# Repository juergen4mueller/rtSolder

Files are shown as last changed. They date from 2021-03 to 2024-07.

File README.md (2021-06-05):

# rtSolder

As I have the full Weller power for business I wanted to have a cheap solution to work with Wellers RT solder tips at home. Small package, a wide input voltage range, simple to use and scaleable power consumption have been targets of my project.
Final solution is a microchip PIC controller, reading the temperature signal which is processed by a TLV333 op amp, controlling a step down converter to regulate temperature and also drive the display.
Output power is adjustable in 10W steps from 10W to 40W. In 10W mode its also possible to use USB power. For higher power a higher voltage is necessary. Voltage maximum is 30V.

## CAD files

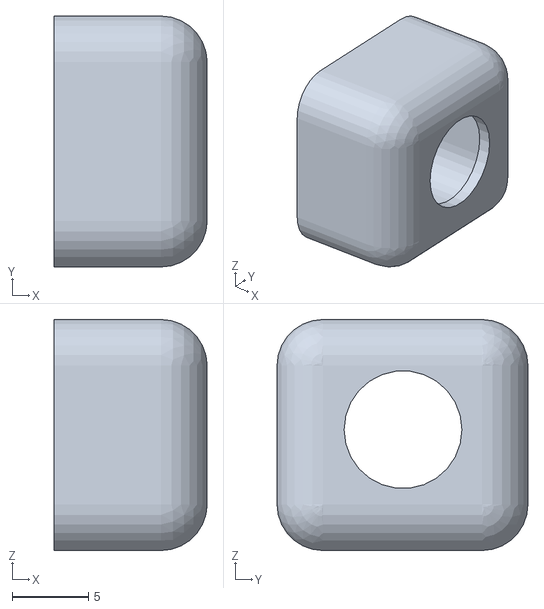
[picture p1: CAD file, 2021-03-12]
Housing/rtSolder_Back.stl
10.0 x 16.4 x 15.1

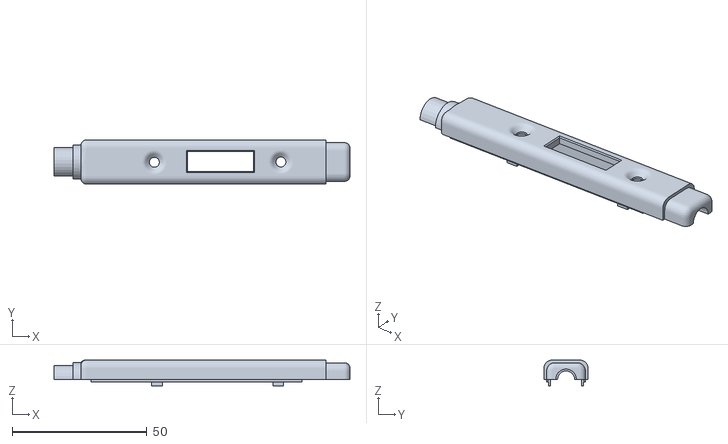
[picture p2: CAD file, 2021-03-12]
Housing/rtSolder_TOP.stl
110.0 x 16.4 x 9.60

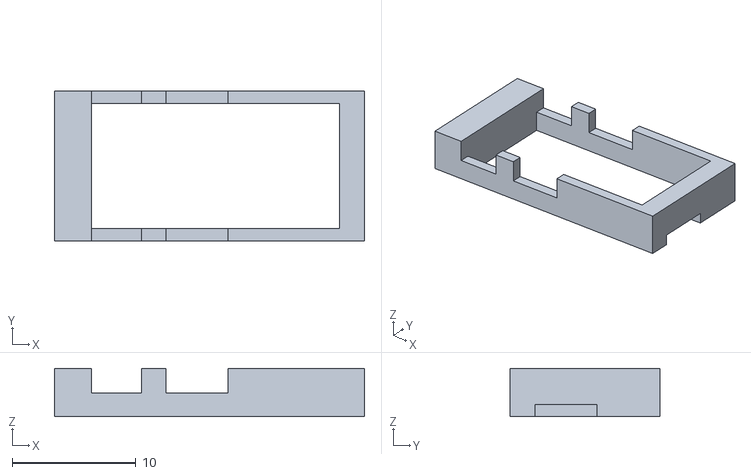
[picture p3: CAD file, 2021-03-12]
Housing/Display_Spacer_light.stl
25.0 x 12.1 x 3.90

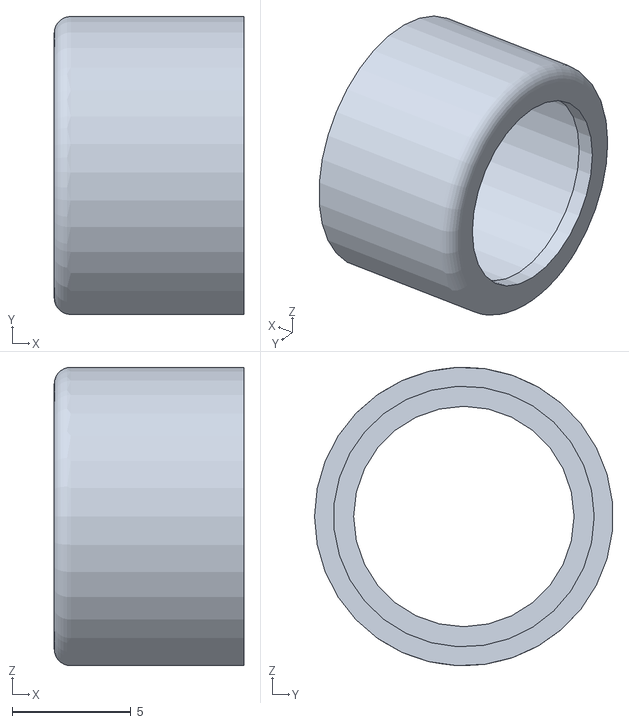
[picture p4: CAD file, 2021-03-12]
Housing/rtSolder_Front.stl
8.00 x 12.6 x 12.6

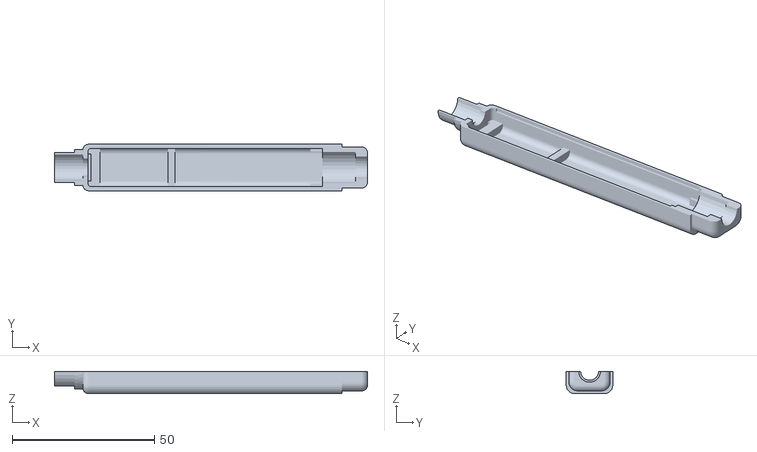
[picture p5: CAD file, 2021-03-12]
Housing/rtSolder_BTM.stl
110.0 x 16.4 x 7.90

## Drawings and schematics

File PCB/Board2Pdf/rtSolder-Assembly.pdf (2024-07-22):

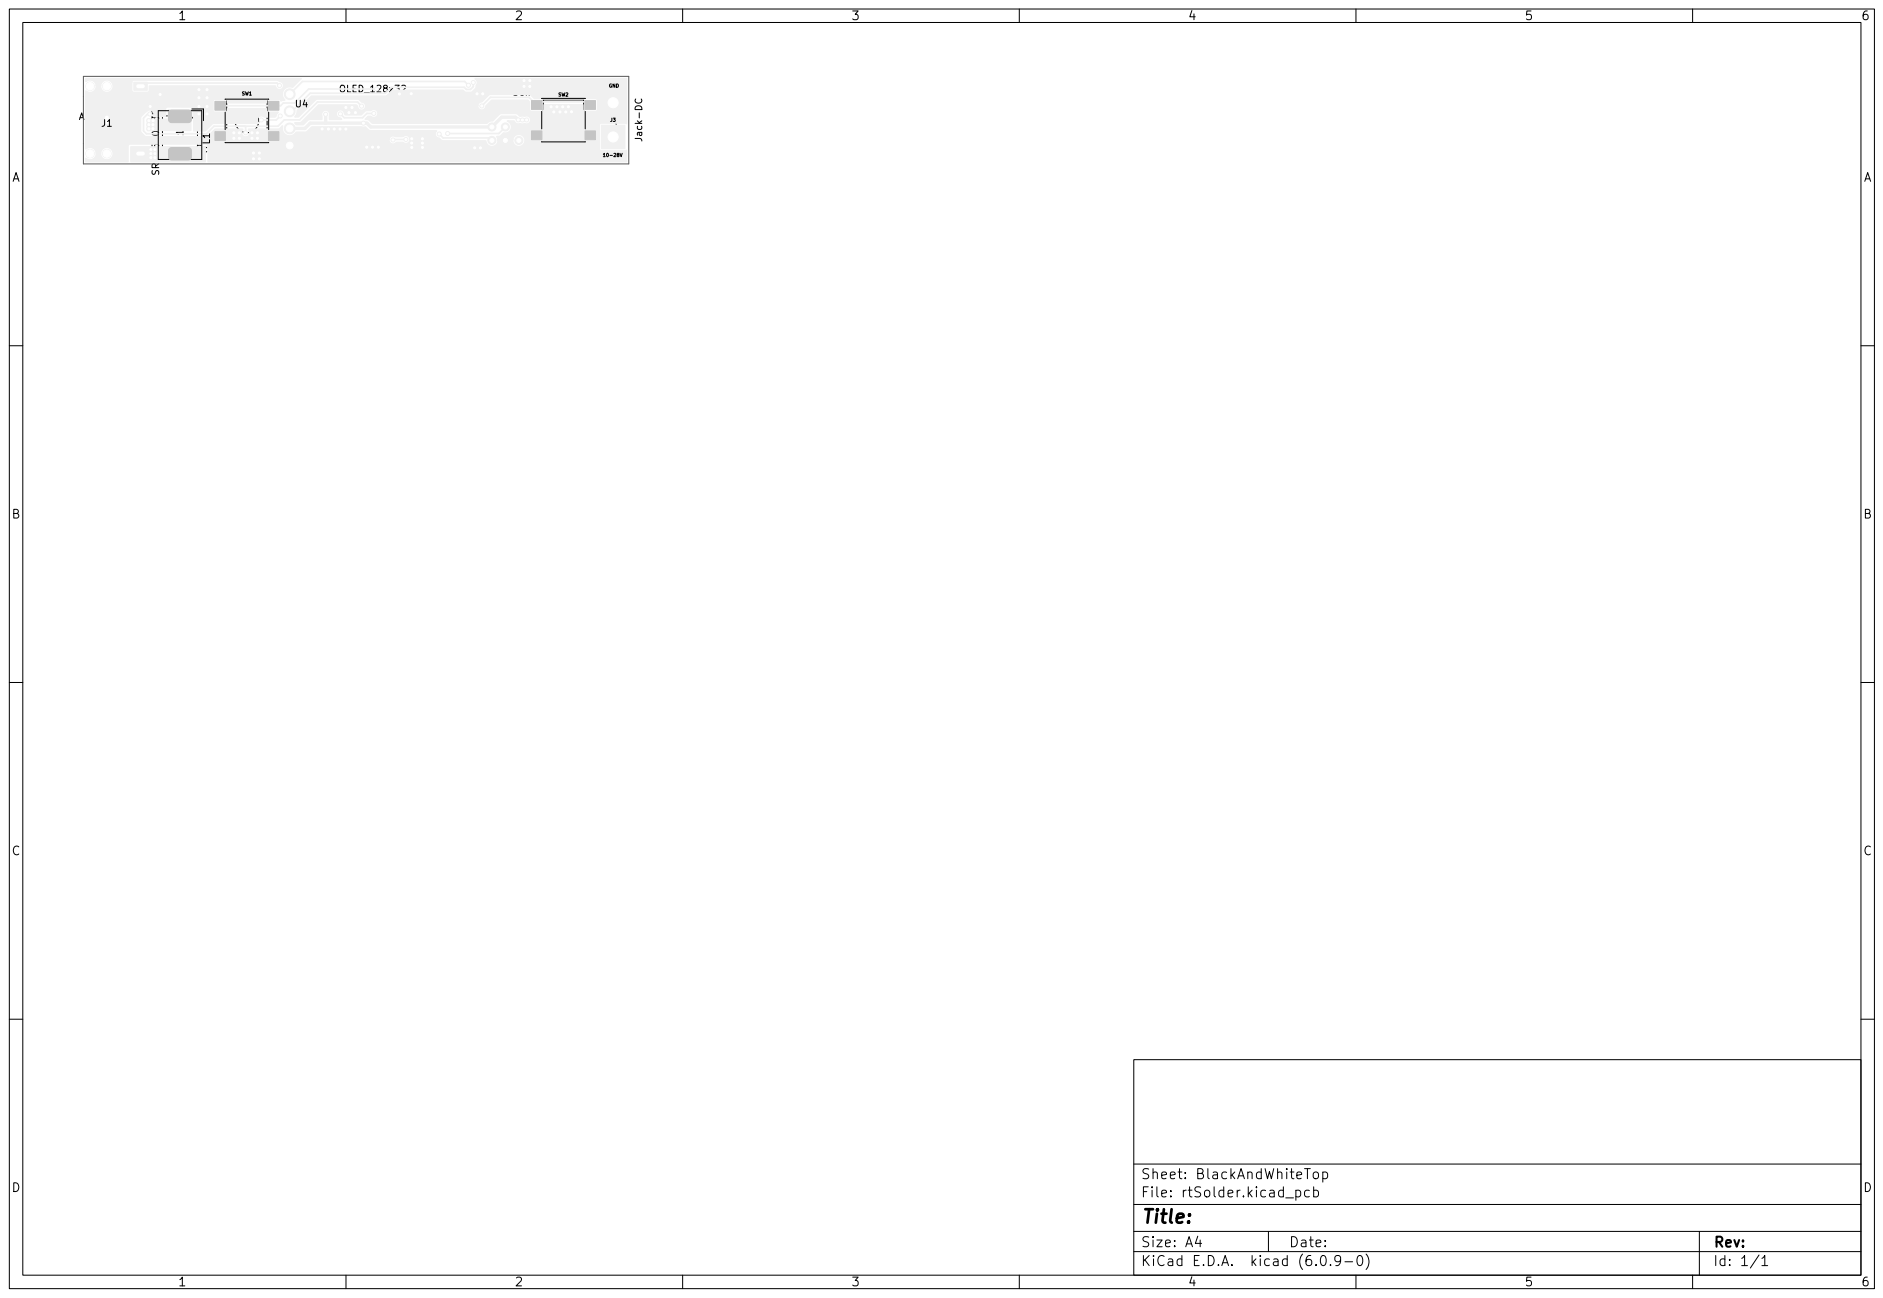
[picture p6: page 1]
D Date: KiCad E.D.A. kicad (6.0.9-0) Size: A4; Rev:; Id: 1/1 Title:; File: rtSolder.kicad_pcb; Sheet: BlackAndWhiteTop SRP⁶⁵⁴⁰⁻³R³M; Schurter_1301.9319 SW2; Jack⁻DC J3 Schurter_1301.9319 SW1 AudioJack3; OLED_128x32; 10-28V GND L1 SW2

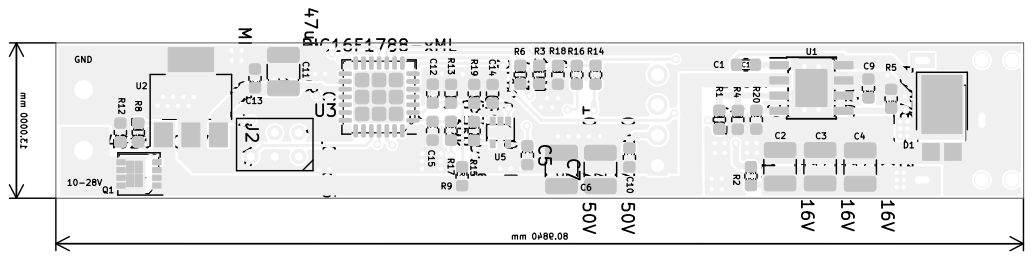
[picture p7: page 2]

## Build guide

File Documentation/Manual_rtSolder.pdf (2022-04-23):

# Bedienungsanleitung rtSolder

Bereich Versorgungsspannung 10 – 33 V
Leistung einstellbar zwischen 10 und 40 Watt (um an das verwendete Netzteil anpassen zu können) Temperatur einstellbar von 150 – 450 °C
DC-Hohlbuchse: 5,5mm/2,1mm
Lötspitze: Weller RT mit 3,5mm Klinkenstecker
Taster 1 | Display | Taster 2

Einschalten: Taster 2 kurz betätigen
Ausschalten: Taster 2 lang betätigen
Im ausgeschalteten Zustand können Leistung und gespeicherte Solltemperatur eingestellt werden. Dazu Taster 1 lang betätigen, bis das Menü erscheint. Hier kann mittels Taster 1 bzw. Taster 2 kurz die gewünschte Temperatur eingestellt werden.
Erneut Taster 1 lang betätigen, um zur Einstellung der Leistung zu gelangen. Hier kann mittels Taster 1 bzw. Taster 2 kurz die gewünschte Leistung eingestellt werden.
Erneut Taster 1 lang betätigen, um die Einstellungen zu speichern.
Mit langer Betätigung von Taster 2 kann das Setup verlassen werden, ohne die Werte zu ändern / speichern.

Im eingeschalteten Zustand kann die Solltemperatur eingestellt werden. Mittels Taster 1 bzw. Taster 2 kurz die gewünschte Temperatur einstellen.

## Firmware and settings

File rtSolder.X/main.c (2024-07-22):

/**
  Generated Main Source File

  Company:
    Microchip Technology Inc.

  File Name:
    main.c

  Summary:
    This is the main file generated using PIC10 / PIC12 / PIC16 / PIC18 MCUs

  Description:
    This header file provides implementations for driver APIs for all modules selected in the GUI.
    Generation Information :
        Product Revision  :  PIC10 / PIC12 / PIC16 / PIC18 MCUs - 1.76
        Device            :  PIC16F1788
        Driver Version    :  2.00
*/

/*
    (c) 2018 Microchip Technology Inc. and its subsidiaries. 
    
    Subject to your compliance with these terms, you may use Microchip software and any 
    derivatives exclusively with Microchip products. It is your responsibility to comply with third party 
    license terms applicable to your use of third party software (including open source software) that 
    may accompany Microchip software.
    
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
    IN NO EVENT WILL MICROCHIP BE LIABLE FOR ANY INDIRECT, SPECIAL, PUNITIVE, 
    INCIDENTAL OR CONSEQUENTIAL LOSS, DAMAGE, COST OR EXPENSE OF ANY KIND 
    WHATSOEVER RELATED TO THE SOFTWARE, HOWEVER CAUSED, EVEN IF MICROCHIP 
    HAS BEEN ADVISED OF THE POSSIBILITY OR THE DAMAGES ARE FORESEEABLE. TO 
    THE FULLEST EXTENT ALLOWED BY LAW, MICROCHIP'S TOTAL LIABILITY ON ALL 
    CLAIMS IN ANY WAY RELATED TO THIS SOFTWARE WILL NOT EXCEED THE AMOUNT 
    OF FEES, IF ANY, THAT YOU HAVE PAID DIRECTLY TO MICROCHIP FOR THIS 
    SOFTWARE.
*/

#include "mcc_generated_files/mcc.h"
#include "OLED/i2c1.h"
#include "OLED/lcd.h"
#include "OLED/font.h"
#include <stdio.h>
#include <string.h>

uint16_t loads_per_minute;
uint16_t time_counter;
uint16_t counter_200ms;
uint8_t counter_minutes;
//#define TEST_POWER_MODULE

__EEPROM_DATA(0x02/*default power*/, 0x35/*default temperature*/, 0x02/*auto off nach 5 min*/, 0xFF, 0xFF, 0xFF, 0xFF, 0xFF); // Fill first 8 bytes of EEPROM
/*            SW1                              SW2
            +++++++++                       +++++++++
 *          +       +    **************     +       +
 *          +   o   +    **************     +   o   +
 *          +       +    **************     +       +
 *          +++++++++                       +++++++++
 
 *          
 *          Menü ON   LP                    ON SP 
 *          Menü Skip LP                    OFF LP
 *          Temperatur -                  Temperatur +  
 * 
 *  Im Menü:
 *  - Solltemperatur gespeichert im EEPROM
 *  - Leistung      gespeichert im EEPROM
 *  - Zeit bis autom. abgeschalten wird
 * 
 * Bei 350 Grad:
 * 10W: 2-3
 * 20W: 4-5
 * 30W: 5-7
 * 40W: 8-10
 * 
 * Bei 400 Grad:
 * 10W: 
 * 20W: 
 * 30W: 
 * 40W: 
 *  
 * 
 */

/*
RC1+RC2 0 -> U = 9,1V P= 41 W (TIP_PS1+TIP_PS2)
RC1 0 ???> U = 7,4V P= 27W (TIP_PS1)
RC2 0 ???> U = 6,1V P= 18W (TIP_PS2)
nichts 0 ??> U = 4,4V P= 10W (kein TIP_PS geschalten)
*/

uint8_t counter2ms_solder, counter2ms_switch;
uint8_t tmr_2ms, tmr1_msg;
uint8_t Switch_1, Switch_2, Switch_1_alt, Switch_2_alt;
uint8_t counter_LP_SW1, counter_LP_SW2;
uint16_t Temperatur_TIP;
uint16_t U_Supply;
uint16_t TEMP_SOLL;
uint16_t AN_out;

uint16_t Temp_Anz_Filter[16];
uint8_t  Temp_Anz_pos;

char text_out[30];

extern uint16_t AN_IN_Temp, AN_IN_U_Supply;

uint8_t counter_left, counter_right;

uint8_t testmode;
uint8_t state_test;

uint8_t mode, mode_alt;
#define mode_startup 0x00
#define mode_off 0x01
#define mode_menue 0x02
#define mode_work  0x03

#define solder_display_normal   0x00
#define solder_display_dev      0x01
uint8_t solder_display_mode;

uint8_t EE_solltemperatur;  // Faktor 10
uint8_t EE_soll_Power;       // Faktor 10
#define Auto_off_disabled   0x00 
#define Auto_off_2_min      0x01
#define Auto_off_5_min      0x02
#define Auto_off_10_min     0x03
#define Auto_off_15_min     0x04
uint8_t EE_AutoOff;         //
uint8_t x;

void timer1_fired(void){
    tmr1_msg ++;
}

void init_system(void){
    counter2ms_solder = 0;
    solder_display_mode = solder_display_normal;
    testmode = 0;
#ifdef TEST_POWER_MODULE
    
#else
    initI2C();
    lcd_init();
#endif
    Temp_Anz_pos = 0;
    mode = mode_startup;
    EE_soll_Power = DATAEE_ReadByte(0x00);
    EE_solltemperatur = DATAEE_ReadByte(0x01);
    EE_AutoOff = DATAEE_ReadByte(0x02);
    
    if(EE_soll_Power > 4){
        EE_soll_Power = 4;
    }
    if(EE_soll_Power < 1){
        EE_soll_Power = 1;
    }
    if(EE_solltemperatur > 45){
        EE_solltemperatur = 35;
    }
    if(EE_AutoOff > Auto_off_15_min){
        EE_AutoOff = Auto_off_15_min;
    }
}


uint16_t calc_tip_temperatur(uint16_t adc_value){
    // ADC-Wert ist 12 Bit lang -> 0...4095
    // mit Referenzspannugn 2.048V (FVR) 500 µV pro Bit
    // Temperaturmessung: bei 450 Grad sind 7mV messbar
    // bei 7mV soll der ADC-Wert 3600 sein -> ADC-Wert / 8 ergibt Temperatur
    // -> 7mV am OP Eingang sollen 1,950 Volt am OP-Ausgang ergeben
    // Verstärkungsfaktor 261 -> 39kOhm und 150 Ohm
    uint16_t calcValue = adc_value;

    return ((calcValue >> 3)+20); // +20 da die Umgebungstemperatur schon 20 Grad beträgt
}
uint16_t calc_supply_voltage(uint16_t adc_value){
    // Messung soll bis 30V gehen (30/4095 = 7,33mV je Bit)
    // 30,0V -> 300 als Ergebnis (2400 / 8)
    // bei 30V sollen 1,2V am ADC anliegen
    // 56kOhm zu 2,2 kOhm -> Messfehler 1,8%
    return (adc_value >> 3);
}

#define sw1_short   0x01
#define sw1_long    0x10
#define sw2_short   0x02
#define sw2_long    0x20
#define sw1_u_sw2   0x04



/*            SW1                              SW2
            +++++++++                       +++++++++
 *          +       +    **************     +       +
 *          +   o   +    **************     +   o   +
 *          +       +    **************     +       +
 *          +++++++++                       +++++++++
 
 *          
 *          Menü ON   LP                    ON SP 
 *          Menü Skip LP                    OFF LP
 *          Temperatur -                  Temperatur +  
 * 
 *  Im Menü:
 *  - Solltemperatur gespeichert im EEPROM
 *  - Max. Strom     gespeichert im EEPROM
 * 
 * 
 * 
 *  OFF 
 * 
 */

unsigned char get_switch_state(void){
    // wird alle 2ms aufgerufen
    static uint8_t sw1, sw2, sw1_alt, sw2_alt;
    static uint8_t sw1_cnt, sw2_cnt;
    static uint8_t sw1_long_done, sw2_long_done;
    static uint8_t counter_switch;
    static uint8_t init_switch;
    uint8_t switch_state = 0;
    
    sw1 = IN_Switch1_GetValue();
    sw2 = IN_Switch2_GetValue();
    counter_switch ++;
    if(counter_switch >= 50){
        counter_switch = 0;
        // alle 100 ms
        init_switch = 1;
        
        if(sw1 == 0)sw1_cnt ++; else sw1_cnt = 0;
        if(sw2 == 0)sw2_cnt ++; else sw2_cnt = 0;
        
        if((sw1_cnt >= 10)&&(sw1_long_done == 0)){ switch_state = sw1_long; sw1_long_done = 1;} // longpress nach 1s
        if((sw2_cnt >= 10)&&(sw2_long_done == 0)){ switch_state = sw2_long; sw2_long_done = 1;} // longpress nach 1s
    }
    if((sw1==1)&&(sw1_alt==0)){
        if(sw1_long_done == 1){
            sw1_long_done = 0;
        }
        else{
            switch_state = sw1_short;
        }
    }
    if((sw2==1)&&(sw2_alt==0)){
        if(sw2_long_done == 1)
        sw2_long_done = 0;
        else
        switch_state = sw2_short;
    }
    
    sw1_alt = sw1;
    sw2_alt = sw2;
    if(init_switch) return switch_state;
    else return 0;
}
unsigned int test_power_to_display;
void proc_off(void){ // and test mode
    uint8_t switch_state = get_switch_state();
    static uint16_t counter_display_2ms;
    counter_display_2ms ++;
    
    if (switch_state == sw1_short) {
        if(testmode == 0){
            counter_left++;
        }
        else{
            testmode = 0;
            counter_display_2ms = 0;
        }
    }
    if(switch_state == sw1_long){    
        if(testmode == 0){
            // Enter Menu
            counter_left = 0;
            mode = mode_menue;
            counter_display_2ms = 0;
        }
        else{
            testmode = 0;
            counter_display_2ms = 0;
        }
    }
    else if(switch_state == sw2_short){   
        if(testmode != 0){
            state_test ++;
        }
        else{
            mode = mode_work;
            counter_left = 0;
            counter_minutes = 0;
            counter_200ms = 0;
            counter_display_2ms = 0;
        }
    }
    else if(switch_state == sw2_long){ 
        if(counter_left == 4){
            if(testmode != 0){
                testmode = 0;
            }
            else{
                testmode = 1;
                counter_200ms = 0;
                state_test = 0;
            }
        }
        else{
            mode = mode_work;
            counter_minutes = 0;
            counter_200ms = 0;
            counter_display_2ms = 0;
        }
        counter_left = 0;
    }
    
    if(testmode==1){
        // <editor-fold defaultstate="collapsed" desc="Testbetrieb">
        counter2ms_solder ++;
        if(counter2ms_solder == 4){
            ADC_StartConversion(AN2_Temp_Tip);
        }
        if(counter2ms_solder == 6){
            if(counter_200ms >= 200){
                state_test = 9; // Test automatisch nach 40 Sekunden beenden
            }
            switch(state_test){
                case 0:
                    test_power_to_display = 0;
                    TIP_SUPPLY_EN_SetLow();
                    TIP_PS1_SetLow();
                    TIP_PS1_SetDigitalInput();
                    TIP_PS2_SetLow();
                    TIP_PS2_SetDigitalInput();
                    break;
                case 1: // 10 Watt
                    test_power_to_display = 10;
                    TIP_SUPPLY_EN_SetHigh();
                    TIP_PS1_SetLow();
                    TIP_PS1_SetDigitalInput();
                    TIP_PS2_SetLow();
                    TIP_PS2_SetDigitalInput();
                    break;
                case 2: //Off
                    test_power_to_display = 0;
                    TIP_SUPPLY_EN_SetLow();
                    TIP_PS1_SetLow();
                    TIP_PS1_SetDigitalInput();
                    TIP_PS2_SetLow();
                    TIP_PS2_SetDigitalInput();
                    break;
                case 3: // 20 Watt
                    test_power_to_display = 20;
                    TIP_SUPPLY_EN_SetHigh();
                    TIP_PS1_SetLow();
                    TIP_PS1_SetDigitalInput();
                    TIP_PS2_SetLow();
                    TIP_PS2_SetDigitalOutput();
                    break;
                case 4: // Off
                    test_power_to_display = 0;
                    TIP_SUPPLY_EN_SetLow();
                    TIP_PS1_SetLow();
                    TIP_PS1_SetDigitalInput();
                    TIP_PS2_SetLow();
                    TIP_PS2_SetDigitalInput();
                    break;
                case 5: // 30 Watt
                    test_power_to_display = 30;
                    TIP_SUPPLY_EN_SetHigh();
                    TIP_PS1_SetLow();
                    TIP_PS1_SetDigitalOutput();
                    TIP_PS2_SetLow();
                    TIP_PS2_SetDigitalInput();
                    break;
                case 6: // Off
                    test_power_to_display = 0;
                    TIP_SUPPLY_EN_SetLow();
                    TIP_PS1_SetLow();
                    TIP_PS1_SetDigitalInput();
                    TIP_PS2_SetLow();
                    TIP_PS2_SetDigitalInput();
                    break;
                case 7: // 40 Watt 
                    test_power_to_display = 40;
                    TIP_SUPPLY_EN_SetHigh();
                    TIP_PS1_SetLow();
                    TIP_PS1_SetDigitalOutput();
                    TIP_PS2_SetLow();
                    TIP_PS2_SetDigitalOutput();
                    break;
                case 8: // Off
                    test_power_to_display = 0;
                    TIP_SUPPLY_EN_SetLow();
                    TIP_PS1_SetLow();
                    TIP_PS1_SetDigitalInput();
                    TIP_PS2_SetLow();
                    TIP_PS2_SetDigitalInput();
                    break;
                case 9:
                    TIP_SUPPLY_EN_SetLow();
                    testmode = 0;
                    state_test = 0;
                    break;
                default:
                    test_power_to_display = 0;
                    TIP_PS1_SetLow();
                    TIP_PS1_SetDigitalInput();
                    TIP_PS2_SetLow();
                    TIP_PS2_SetDigitalInput();
                    break;
            }
        }
        if(counter2ms_solder >= 100){
            counter2ms_solder = 0;
            counter_200ms ++;
            TIP_SUPPLY_EN_SetLow();
            Temperatur_TIP = calc_tip_temperatur(AN_IN_Temp);
            U_Supply = calc_supply_voltage(AN_IN_U_Supply);
            fb_clear();
            //gemessene Versorgungsspannung
            sprintf(text_out, "%2d.%dV", (U_Supply / 10), U_Supply % 10);
            fb_draw_string_big(0, 0, text_out);
            // eingestellte Leistung
            sprintf(text_out, "%2dW", test_power_to_display);
            fb_draw_string_big(64, 0, text_out);
            // solder breaks
            sprintf(text_out, "Test");
            fb_draw_string_big(0, 2, text_out);

            // Ist-Temperatur
            if (Temperatur_TIP < 500) {
                sprintf(text_out, "%3dC", Temperatur_TIP);
            } else {
                sprintf(text_out, "TIP!");
            }
            fb_draw_string_big(64, 2, text_out);

            fb_show();             
            // </editor-fold>
        }
    }
    else{
        TIP_SUPPLY_EN_SetLow();
        if(counter_display_2ms >= 500){  
            U_Supply = calc_supply_voltage(AN_IN_U_Supply);
            counter_display_2ms = 0;
            fb_clear();
            fb_draw_char_super_big(0, 0, BIG_CHAR_SETUP); // Setup-Symbol links
            fb_draw_char_super_big(40, 1, BIG_CHAR_O); // 'O'
            fb_draw_char_super_big(55, 1, BIG_CHAR_F); // 'F'
            fb_draw_char_super_big(70, 1, BIG_CHAR_F); // 'F'
            fb_draw_char_super_big(112, 0, BIG_CHAR_ON_OFF); // ON-OFF-Symbol rechts           
            sprintf(text_out, "%2dW/%2d,%1dV", EE_soll_Power * 10, U_Supply/10, U_Supply%10);
            fb_draw_string(40, 0, text_out);
            fb_show();
            ADC_StartConversion(AN2_Temp_Tip);
        }
    }
}
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
void main(void)
{
    // initialize the device
    SYSTEM_Initialize();

    // Enable the Global Interrupts
    INTERRUPT_GlobalInterruptEnable();

    // Enable the Peripheral Interrupts
    INTERRUPT_PeripheralInterruptEnable();

    init_system();
    TMR1_SetInterruptHandler(&timer1_fired);
    
    TMR1_StartTimer();
    TIP_SUPPLY_EN_SetDigitalOutput();
    
      fb_show();
    __delay_ms(1000); // Delay nach einblenden Start-Screen //
  
    TEMP_SOLL = EE_solltemperatur * 10;
    while (1)
    {        
        // Aufruf der Routine alle 2ms
        if(tmr_2ms != tmr1_msg){
            tmr_2ms ++; 
            
            switch (mode){
                case mode_startup: // warten bis Taster betätigt wurde
                    if(get_switch_state()){
                        mode = mode_off;
                    }
                    mode = mode_off;
                    break;
                case mode_off: // AUS-Zustand
                    proc_off();
                    break;                
                case mode_work: // normaler Betrieb
                    proc_solder();
                    break;                
                case mode_menue: // Setup-Mode
                    TIP_SUPPLY_EN_SetLow();
                    proc_menue();
                    break;
                default:
                    mode = 0;
                    break;
            }
        }    
    }
}

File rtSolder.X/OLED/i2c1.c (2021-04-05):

/*******************************************************************************
 * File:        peri.c
 * Project:     SP18 - I2C OLED Display
 * Author:      Nicolas Pannwitz
 * Version:     
 * Web:         http://pic-projekte.de
 ******************************************************************************/

#include <xc.h>
#include <stdint.h>
#include "i2c1.h"

/*******************************************************************************
 * I2C
 */

void initI2C(void)
{
    /* Zugehörige Tris-Bits auf Input schalten */
    /* Master-Mode - Clock = Fosc / (4*(SSPxADD+1)) */  
    /* SSPxADD values of 0, 1 or 2 are not supported for I2C Mode */
        
    SSP1CON1bits.SSPM3 = 1;
    SSP1CON1bits.SSPM2 = 0;
    SSP1CON1bits.SSPM1 = 0;
    SSP1CON1bits.SSPM0 = 0;
    SSP1CON1bits.SSPEN = 1;
    SSP1ADD = 0x13;                      // für 200kHz (Fosc = 8 MHz)
    SSP1CON2bits.ACKDT = 0;
}

void waitI2C(void)
{
    while(!PIR1bits.SSP1IF);          // Aktion* wurde beendet
    PIR1bits.SSP1IF = 0;              // Flag zurücksetzten
} 
 
// *Zum Beispiel: START-Sequenze, Übertragung von 8 Bit, ...

void idleI2C(void)
{
    while( SSP1STATbits.R_nW );        // Läuft eine Übertragung?
    while( SSP1CON2 & 0x1F );         // Ist irgendwas anderes aktiv?
}

void startI2C(void)
{
    idleI2C();                        // Ist der Bus frei?
    SSP1CON2bits.SEN = 1;             // Auslösen einer START-Sequenze
    while( SSP1CON2bits.SEN );        // Beendet, wenn SEN gelöscht wurde*
}
 
//void restartI2C(void)
//{
//    idleI2C();                        // Ist der Bus frei?
//    SSP1CON2bits.RSEN=1;              // Auslösen einer RESTART-Sequenze
//    while( SSP1CON2bits.RSEN );       // Beendet, wenn RSEN gelöscht wurde*
//}
 
void stopI2C(void)
{
    idleI2C();                        // Ist der Bus frei?
    SSP1CON2bits.PEN = 1;             // Auslösen einer RESTART-Sequenze
    while( SSP1CON2bits.PEN );        // Beendet, wenn RSEN gelöscht wurde*
}
 
// *Oder das Bit SSPxIF gesetzt wurde (siehe Datenblatt)

uint8_t sendI2C(uint8_t byte)
{
    idleI2C();                        // Ist der Bus verfügbar?
    PIR1bits.SSP1IF = 0;              // Flag löschen (wird in waitI2C() abgefragt)
    SSP1BUF = byte;                   // Durch füllen des Puffers Sendevorgang auslösen
    waitI2C();                        // Warten bis Übertragung abgeschlossen ist
 
    return ~SSP1CON2bits.ACKSTAT;     // Return 1: ACK empfangen, 0: kein ACK empfangen
}

//uint8_t reciveI2C_nack(void)
//{
//    uint8_t incomming = 0;            // Einlesepuffer
// 
//    idleI2C();                        // Ist der Bus verfügbar?
//    PIR1bits.SSP1IF = 0;              // Flag löschen (wird in waitI2C() abgefragt)
//    SSP1CON2bits.RCEN = 1;            // Als Empfänger konfigurieren (wird autom. wieder gelöscht)
//    waitI2C();                        // Warten bis Übertragung (lesend) abgeschlossen ist
//    SSP1CON2bits.ACKDT = 1;           // Mit NACK quitieren (Nicht weiter einlesen)
//    SSP1CON2bits.ACKEN = 1;           // NACK aussenden
//    while( SSP1CON2bits.ACKEN );      // NACK abgeschlossen?
//    incomming = SSP1BUF;              // Empfangenes Byte in den Puffer
//        
//    return incomming;                 // Und zurück geben
//}
// 
//uint8_t reciveI2C_ack(void)
//{
//    uint8_t incomming = 0;            // Einlesepuffer
// 
//    idleI2C();                        // Ist der Bus verfügbar?
//    PIR1bits.SSP1IF = 0;              // Flag löschen (wird in waitI2C() abgefragt)
//    SSP1CON2bits.RCEN = 1;            // Als Empfänger konfigurieren (wird autom. wieder gelöscht)
//    waitI2C();                        // Warten bis Übertragung (lesend) abgeschlossen ist
//    SSP1CON2bits.ACKDT = 0;           // Mit AACK quitieren (weiter einlesen)
//    SSP1CON2bits.ACKEN = 1;           // ACK aussenden
//    while( SSP1CON2bits.ACKEN );      // ACK abgeschlossen?
//    incomming = SSP1BUF;              // Empfangenes Byte in den Puffer
// 
//    return incomming;                 // Und zurück geben
//}

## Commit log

2021-03-12 Initial Commit
    Initial commit
    [Display_Spacer_light.stl, rtSolder.kicad_pcb, rtSolder.sch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]
2021-03-16 adjust temp measurement
    changed R19 to 150R
    [rtSolder.kicad_pcb, rtSolder.sch]
2021-03-22 Screen Update
    Cleaned up the screens and added new way to enter debug and test mode
    [rtSolder-B_Cu.gbr, rtSolder-B_Mask.gbr, rtSolder-B_SilkS.gbr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]
2021-04-18 Release V1.1 -Accurate temperature measurement -auto-off feature implemented
2022-04-23 update der Doku
    [Display_Spacer_light.stl, rtSolder.kicad_pcb, rtSolder.sch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]
2024-07-22 last modifications
    [rtSolder.kicad_pcb, rtSolder.kicad_sch]
